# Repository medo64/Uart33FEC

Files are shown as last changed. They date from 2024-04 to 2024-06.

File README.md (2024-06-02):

[UART 3.3V Framework Expansion Card](https://medo64.com/uart33fec/)
===================================================================

This Framework laptop expansion card will show up on your system as a serial
device and allow for a non-isolated serial UART communication up to 1 Mbaud
baud rate.

Please note that this card is not using RS-232 but 3.3V TTL.

## UART Pinout

To connect to this board, one has to use a 4-pin JST XH connector. The following
table represents the pinout, pin 1 being on the left as looking into the
expansion card.

| # | Ref | Description |
|--:|:---:|---|
| 2 | GND | Ground connection |
| 1 | RXD | Receive (3.3V TTL) |
| 3 | TXD | Transmit (3.3V TTL) |
| 4 | 3V3 | 3.3V 400mA (typical) output |

Using 22 AWG wire 0.25 mm² is recommended.

## Supported Speeds

This board employs the FT232R as its UART chip, and consequently, it supports
all the baud rates this chip [can handle](https://ftdichip.com/Documents/AppNotes/AN232B-05_BaudRates.pdf).
The table below lists the standard baud rates.

| Baud rate | Actual | Error | Divisor |
|---:|---:|---:|---:|
| 300 | 300 | 0.00% |  10000.000 |
| 600 | 600 | 0.00% | 5000.000 |
| 1,200 | 1,200 | 0.00% | 2500.000 |
| 1,800 | 1,800 | 0.00% | 1666.625 |
| 2,400 | 2,400 | 0.00% | 1250.000 |
| 4,800 | 4,800 | 0.00% | 625.000 |
| 7,200 | 7,201 | 0.01% | 416.625 |
| 9,600 | 9,600 | 0.00% | 312.500 |
| 14,400 | 14,406 | 0.04% | 208.250 |
| 19,200 | 19,200 | 0.00% | 156.250 |
| 28,800 | 28,812 | 0.04% | 104.125 |
| 38,400 | 38,400 | 0.00% | 78.125 |
| 57,600 | 57,692 | 0.16% | 52.000 |
| 115,200 | 115,385 | 0.16% | 26.000 |
| 230,400 | 230,769 | 0.16% | 13.000 |
| 460,800 | 461,538 | 0.16% | 6.500 |
| 921,600 | 923,077 | 0.16% | 3.250 |
| 1,000,000 | 1,000,000 | 0.00% | 3.000 |

While chip does support baud rates up to 3 Mbaud, granularity of such rates
is severely limited.

---
*You can check my blog and other projects at [www.medo64.com](https://www.medo64.com/electronics/).*

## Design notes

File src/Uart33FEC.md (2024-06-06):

### Uart33FEC

#### Parts

|  # | Part | RefDes  | Preferred Part Number |
|---:|---|---|---|
|  2 | C 47pF NP0 16V (0805) | C1-C2 | 399-C0805C470J5GAC7800CT-ND |
|  1 | C 10nF X7R 16V (0805) | C3 | 399-17617-1-ND |
|  3 | C 100nF X7R 16V (0805) | C4-C6 | 478-5311-1-ND |
|  5 | C 10uF X5R 16V (0805) | C7-C11  | 1276-1096-1-ND |
|  1 | D Schottky 30V 800mA [CUS08F30,H3F] (SOD323) | D1 | CUS08F30H3FCT-ND |
|  1 | D TVS 3.3V D1213A-02SOL-7 (SOT23-3) | D2 | D1213A-02SOL-7DICT-ND |
|  2 | DS LED (0805) | DS1-DS2 | 475-1415-1-ND |
|  1 | J USB C, plug, straddle 0.8mm | J1 | WM12855-ND |
|  1 | J JST XH Vertical (4w) | J2 | 455-B4B-XH-A-ND |
|  1 | L Ferrite 600R@100Mhz | L1 | 240-2390-1-ND |
|  2 | R 27 1% (0805) | R1-R2 | 738-RMCF0805FT27R0CT-ND |
|  2 | R 1K 0.125W (0805) | R3-R4 | RMCF0805FT1K00CT-ND |
|  1 | R 5.1K 0.125W (0805) | R5 | RMCF0805FT5K10CT-ND |
|  1 | R 10K 0.125W (0805) | R6 | RMCF0805FT10K0CT-ND |
|  1 | R 75K 0.125W (0805) | R7 | RMCF0805FT75K0CT-ND |
|  1 | U Transciever Uart FT230XS (SSOP-16) | U1 | 768-1154-5-ND |
|  1 | U LoadSwitch Adjustable [AP22652W6-7] (SOT23-6) | U2 | 31-AP22652W6-7CT-ND |
|  1 | VR Linear 3.3V 1000mA AZ1117IH-3.3TRG1 (SOT223) | VR1 | AZ1117IH-3.3TRG1DICT-ND |
|  2 | H Screw M2x3mm | - | - |

#### Specifications

| Property | Value |
|---|---|
| PCB size | 24.0 x 27.9 x 0.8 mm (1.1 in²) |
| Voltage (in) | 5 V ±10% |
| Current (in) | 450 mA (max) |
| Voltage (out) | 5 V ±15% |
| Current (limit) | 400 mA ±10% |

#### FTDI Configuration

| Setting | Value  |
|---|---|
| CBUS0 | TXDEN  |
| CBUS1 | TXLED# |
| CBUS2 | RXLED# |
| CBUS3 | PWREN# |

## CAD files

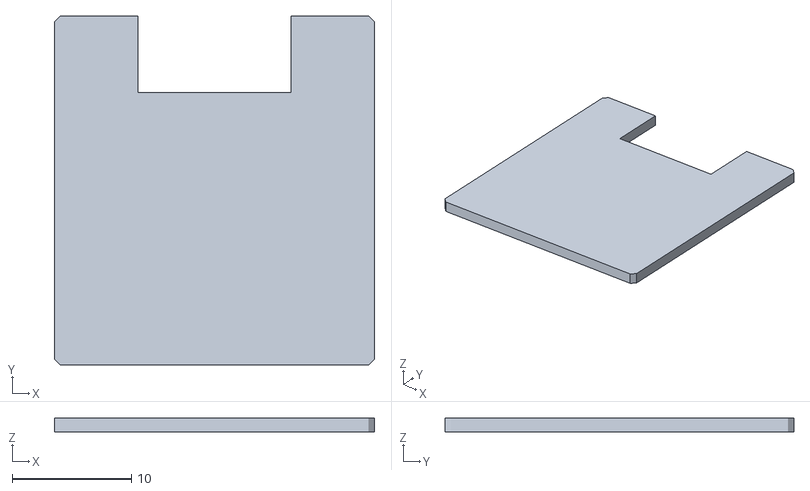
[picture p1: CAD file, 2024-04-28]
src/case/Uart33FEC Case Top.stl
26.9 x 29.3 x 1.20

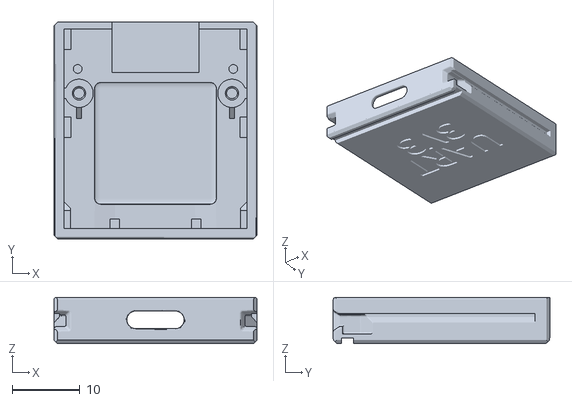
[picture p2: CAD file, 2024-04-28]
src/case/Uart33FEC Case Base.stl
30.0 x 32.0 x 6.80

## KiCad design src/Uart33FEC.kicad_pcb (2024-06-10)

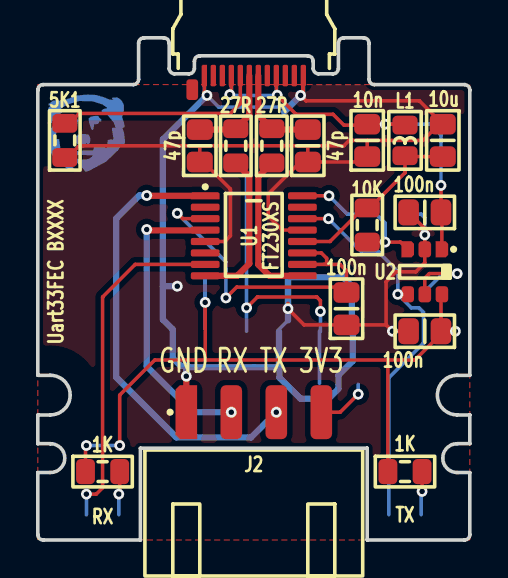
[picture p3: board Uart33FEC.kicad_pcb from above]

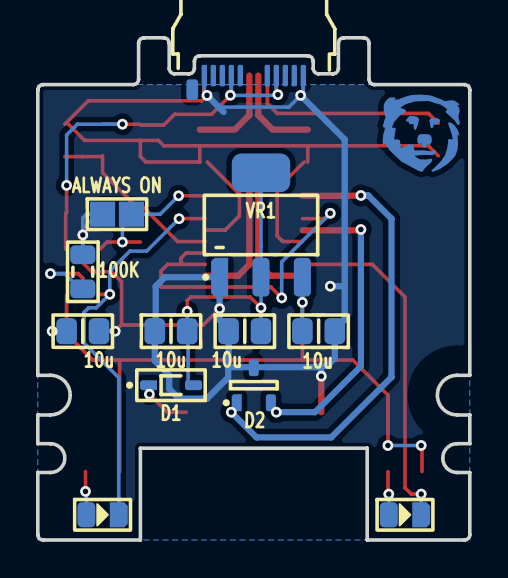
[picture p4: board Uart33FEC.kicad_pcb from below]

Board: 2 copper layers, 24.0 x 27.9 mm, 30 parts (12 on the bottom side), 20 nets.

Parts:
C1, C2: 47p; C (0805)
C3: 10n; C (0805)
C4, C5, C6: 100n; C (0805)
C7, C8, C9, C10, C11: 10u; C (0805)
D1: CUS08F30; D (SOD323)
D2: SM05T1G; D TVS 3.3V [D1213A-02SOL-7] (SOT23-3)
DS1: RX; DS (0805)
DS2: TX; DS (0805)
ICON: Medo64; ICON Medo64
J1: 105444-0001; J USB C 3.2 Edge (24w)
J2: B4B-XH-A; J JST XH Edge [UART] (4w)
JP1: ALWAYS ON; JP (0805)
L1: 600R; L (0805)
R1, R2: 27R; R (0805)
R3, R4: 1K; R (0805)
R5: 5K1; R (0805)
R6: 10K; R (0805)
R7: 100K; R (0805)
U1: FT230XS; U Transceiver UART [FT230XS] (SSOP-16)
U2: AP22652; U LoadSwitch Adjustable [AP22652W6-7] (SOT23-6)
VR1: AZ1117IH; VR Linear 3.3V 1000mA [AZ1117IH-3.3TRG1] (SOT223)

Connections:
3V3: C4.2, U1.3, U1.10, U1.11
3V3_OUT: D1.1, J2.4
3V3_SWITCHED: C10.1, C11.1, D1.2, VR1.2
5V: C7.2, L1.1, R6.1, U1.12
5V_SWITCHED: C6.1, C8.1, C9.1, R3.1, R4.1, U2.6, VR1.3
5V_USB: C3.2, C5.1, J1.A4, J1.A9, J1.B04, J1.B09, L1.2, U2.1
GND: C1.1, C2.1, C3.1, C4.1, C5.2, C6.2, C7.1, C8.2, C9.2, C10.2, C11.2, D2.3, J1.A1, J1.A12, J1.B01, J1.B12, J2.1, JP1.2, R5.1, R7.2, U1.5, U1.13, U2.2, VR1.1
ILIM: R7.1, U2.5
LED_RX: DS1.1, U1.7
LED_RX': DS1.2, R3.2
LED_TX: DS2.1, U1.14, U2.4
LED_TX': DS2.2, R4.2
PWREN#: JP1.1, R6.2, U1.16, U2.3
RX: D2.2, J2.2, U1.4
TX: D2.1, J2.3, U1.1
USB_CC: J1.A5, R5.2
USB_DM: C2.2, J1.A7, R2.2
USB_DM': R2.1, U1.9
USB_DP: C1.2, J1.A6, R1.2
USB_DP': R1.1, U1.8

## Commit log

2024-05-11 Updated type-C connector to allow for more soldermask
    [Uart33FEC.kicad_pcb]
2024-06-02 Fixed max power
2024-06-02 Changed pinout to GND RXD TXD 3V3
    [Uart33FEC.kicad_pcb]
2024-06-02 Changed load switch (400mA limit)
    [Uart33FEC.kicad_pcb]
2024-06-06 Refactored output handling
    [Uart33FEC.kicad_pcb]
2024-06-10 Connected 3V3 output lines
    [Uart33FEC.kicad_pcb]
